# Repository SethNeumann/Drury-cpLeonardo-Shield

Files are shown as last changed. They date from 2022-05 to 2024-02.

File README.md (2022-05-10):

# REPO NAME: Drury-cpLeonardo-Shield

## License: Creative Commons Attribution-NonCommercial-ShareAlike

The original cpNode used a Leonardo-based protoyping board called a BB-Leo.  Chuck Catania like Leonardo because the
2nd serial port made for easier serial debugging as the cpNode needed D0/D1 (TX/RX) to implement the CMRINet.  In 2021
Modern Device discontinued the BB-Leo, so we moved the basic cpNode to the ProMini resulting in the cpNode-PM, we also made 
an adapter board with a Pro-Mini that fit into a standard cpNode, called a BB-ProMini.

Dennis Drury like the Leonardo and wanted to keep the code compatible, so he designed this shield form factor board that 
plugs onto a standard (Uno form factor) Leonardo.  It supports the I2C chain so you can use standard IOXs (or any other
shield you like if you want to write customer code).  

This is a great complement to cpNode, cpNode-PM, Andrew Deak's MegaNode and of course the classic JLC SMINI and SUSIC.

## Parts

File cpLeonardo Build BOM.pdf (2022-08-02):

Qty | Value | Device | Package | Parts | Description
| 1 0.1uF | CAPPTH2 | C-PTH-0.100 | C1
| 4 0.01uF | CAPPTH2 | C-PTH-0.100 | C2, C3, C4, C5
| 3 0.100 | CONNECTOR-M06SIP_LOCK | 1X06-SIP_LOCK | CON4, CON6, CON7 | Arduino Header 6 Standard 6-pin 0.1 header"
| 1 1N4148 | DIODE1N4148 | DIODE-1N4148 | D1 | Diode
| 1 0.100 | M02POLAR_LOCK | MOLEX-1X4_LOCK | GND, LEDCOM | Header 2
| 1 0.100 | PINHD-1X4/90 | 1X04/90 | I2CHDR | right angle I2C headers
| 4 0.100 | M081X08 | 1X08 | IO1, IO2, IO3, IO5 | machine pin header for resistors
2 0.100 | CONNECTOR-M08LOCK_LONGPADS | 1X08_LOCK_LONGPADS J1, J2 | input/output screw terminals
1 | CONN_08SILK_FEMALE_PTH | 1X08 | CON5 | Multi connection point.
| 1 12k | RPTH04 | AXIAL-0.4-RES | R1 | Resistor (Auto RTS - see schemativ)
| 1 470 | RPTH04 | AXIAL-0.4-RES | R2 | Resistor
| 0 0.156 | CONNECTOR-CMRINET.156 | KK-156-5 | RS485-1, RS485-2 | CMRINet Top 3.5mm Screw Terminal 5 pos
| 2 3.5mm | CONNECTOR-CMRINET3.5MM | CMRINET-3.5MM | RS485-3, RS485-4 | CMRINet Top 3.5mm Screw Terminal 5 pos
| 1 G | LEDLED3MM | LED3MM | TX
1 MAX3465CPD MAX3465CPD | DIL14 | U1 | +5V, Fail-Safe, 40Mbps, Profibus RS-485/RS-422 Transceivers
| 1 NE555P | NE555P | DIL-08 | U2 | General purpose bipolar Timer
| 1 8 pin | socket | DIL8
| 1 14 pin | socket | DIL14
| 1 cpLeonardo | board | Uno Shield

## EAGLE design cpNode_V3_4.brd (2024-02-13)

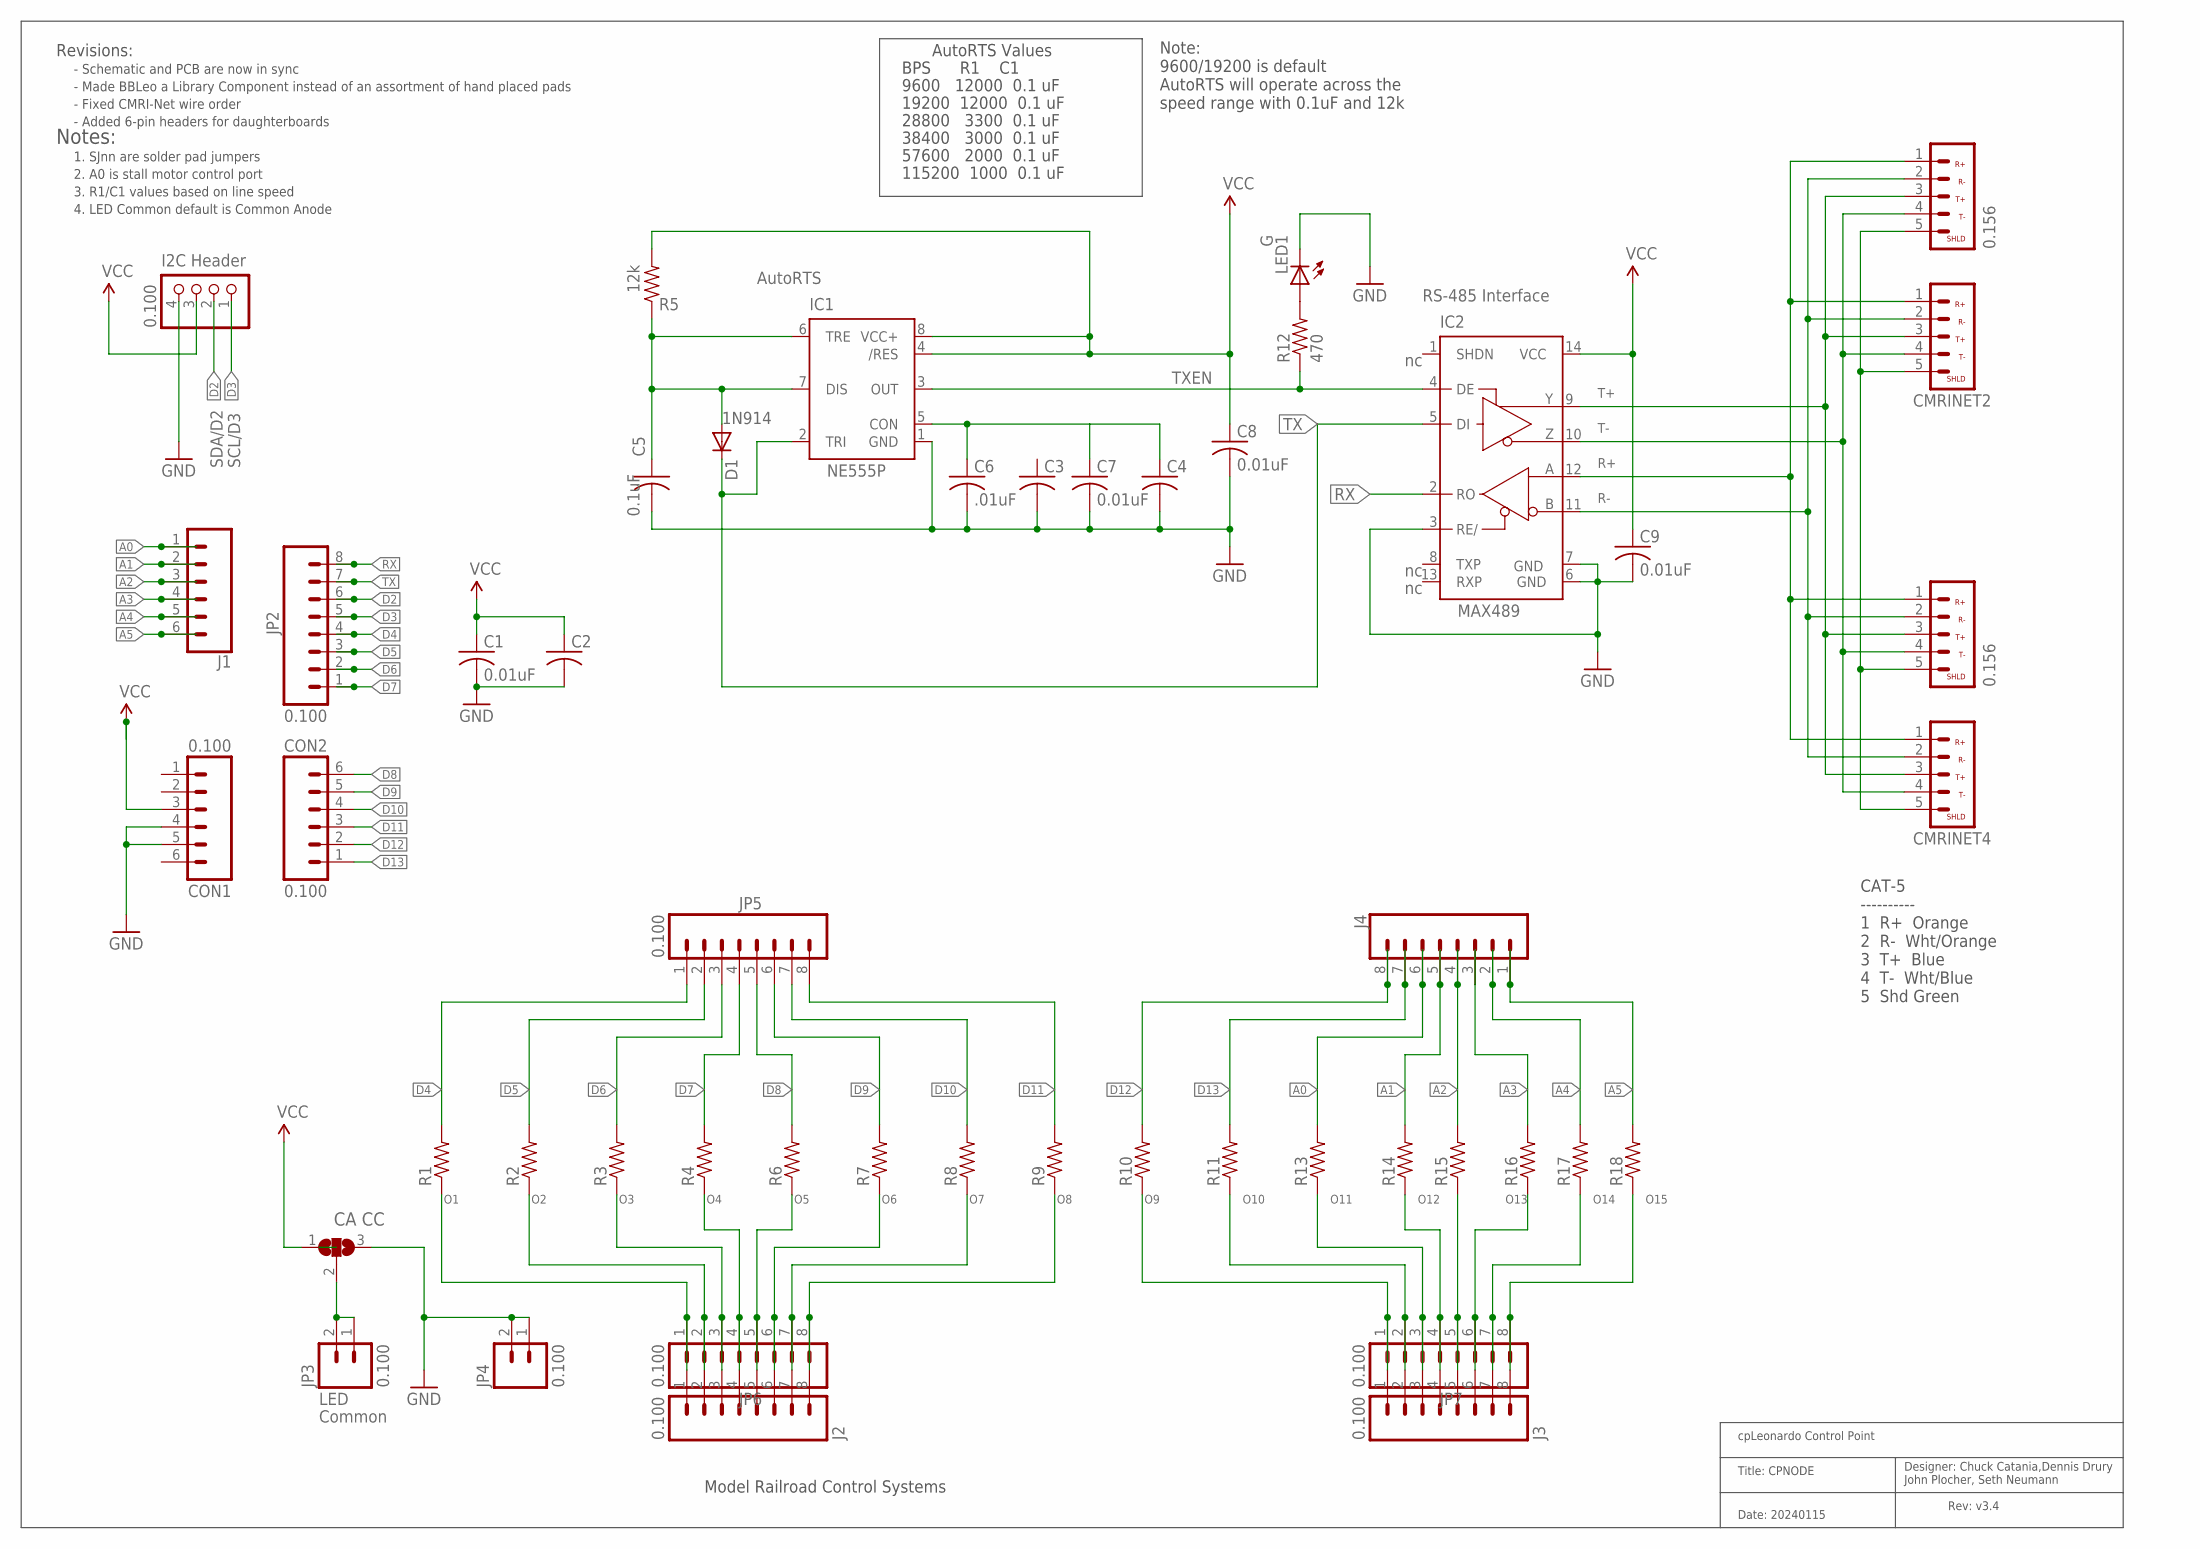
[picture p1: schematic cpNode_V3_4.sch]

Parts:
C1, C7, C8, C9: 0.01uF; C-PTH-0.100
C2, C3, C4: CAPPTH1; C050-024X044
C5: 0.1uF; C-PTH-0.100
C6: .01uF; C050-024X044
CMRINET1, CMRINET3: 0.156; KK-156-5
CMRINET2, CMRINET4: 3.5mm; CMRINET-3.5MM
CON1, CON2: 0.100; 1X06-SIP_LOCK
D1: 1N4148; DIODE-1N4148
IC1: NE555P; DIL-08
IC2: MAX3465CPD; DIL14
J1: CONN_06SILK_FEMALE_PTH; 1X06
J2, J3: 0.100; 1X08_LOCK_LONGPADS
J4: CONN_08"; 1X08
JP1: 0.100; 1X04/90
JP2, JP5, JP6, JP7: 0.100; 1X08
JP3, JP4: 0.100; MOLEX-1X2_LOCK
LED1: G; LED3MM
P1: CA CC; 3P-SMD-2X4.8
R1, R2, R3, R4, R6, R7, R8, R9, R10, R11, R13, R14, R15, R16, R17, R18: RPTH-R0; CUT-R
R5: 12k; AXIAL-0.4-RES
R12: 470; AXIAL-0.4-RES

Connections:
A0: J1.1, J4.6, R13.P1 (2)
A1: J1.2, J4.5, R14.P1 (2)
A2: J1.3, J4.4, R15.P1 (2)
A3: J1.4, J4.3, R16.P1 (2)
A4: J1.5, J4.2, R17.P1 (2)
A5: J1.6, J4.1, R18.P1 (2)
D2: JP1.2, JP2.6
D3: JP1.1, JP2.5
D4: JP2.4, JP5.1, R1.P1 (2)
D5: JP2.3, JP5.2, R2.P1 (2)
D6: JP2.2, JP5.3, R3.P1 (2)
D7: JP2.1, JP5.4, R4.P1 (2)
D8: CON2.6, JP5.5, R6.P1 (2)
D9: CON2.5, JP5.6, R7.P1 (2)
D10: CON2.4, JP5.7, R8.P1 (2)
D11: CON2.3, JP5.8, R9.P1 (2)
D12: CON2.2, J4.8, R10.P1 (2)
D13: CON2.1, J4.7, R11.P1 (2)
GND: C1.2, C2.2, C3.2, C4.2, C5.2, C6.2, C7.2, C8.2, C9.2, CON1.4, CON1.5, IC1.1 (GND), IC2.3 (RE/), IC2.6 (GND), IC2.7 (GND), JP1.4, JP4.1, JP4.2, LED1.K (C), P1.3
unnamed: LED1.A, R12.P$2 (2)
unnamed: C4.1, C6.1, C7.1, IC1.5 (CON)
unnamed: JP3.1, JP3.2, P1.2
unnamed: C5.1, D1.A, IC1.6 (TRE), IC1.7 (DIS), R5.P$1 (1)
unnamed: IC1.3 (OUT), IC2.4 (DE), R12.P$1 (1)
O1: J2.1, JP6.1, R1.P2 (1)
O2: J2.2, JP6.2, R2.P2 (1)
O3: J2.3, JP6.3, R3.P2 (1)
O4: J2.4, JP6.4, R4.P2 (1)
O5: J2.5, JP6.5, R6.P2 (1)
O6: J2.6, JP6.6, R7.P2 (1)
O7: J2.7, JP6.7, R8.P2 (1)
O8: J2.8, JP6.8, R9.P2 (1)
O9: J3.1, JP7.1, R10.P2 (1)
O10: J3.2, JP7.2, R11.P2 (1)
O11: J3.3, JP7.3, R13.P2 (1)
O12: J3.4, JP7.4, R14.P2 (1)
O13: J3.5, JP7.5, R15.P2 (1)
O14: J3.6, JP7.6, R16.P2 (1)
O15: J3.7, JP7.7, R17.P2 (1)
O16: J3.8, JP7.8, R18.P2 (1)
R+: CMRINET1.1, CMRINET2.1, CMRINET3.1, CMRINET4.1, IC2.12 (A)
R-: CMRINET1.2, CMRINET2.2, CMRINET3.2, CMRINET4.2, IC2.11 (B)
RX: IC2.2 (RO), JP2.8
SHIELD: CMRINET1.5, CMRINET2.5, CMRINET3.5, CMRINET4.5
T+: CMRINET1.3, CMRINET2.3, CMRINET3.3, CMRINET4.3, IC2.9 (Y)
T-: CMRINET1.4, CMRINET2.4, CMRINET3.4, CMRINET4.4, IC2.10 (Z)
TX: D1.C, IC1.2 (TRI), IC2.5 (DI), JP2.7
VCC: C1.1, C2.1, C8.1, C9.1, CON1.3, IC1.4 (/RES), IC1.8 (VCC+), IC2.14 (VCC), JP1.3, P1.1, R5.P$2 (2)

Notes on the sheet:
Rev: v3.4
Date: 20240115
Title: CPNODE
cpLeonardo Control Point
Designer: Chuck Catania,Dennis Drury John Plocher, Seth Neumann
SDA/D2
SCL/D3
TXEN
LED
1N914
MAX489
RS-485 Interface
Notes:
1. SJnn are solder pad jumpers
2. A0 is stall motor control port
I2C Header
3. R1/C1 values based on line speed
AutoRTS
AutoRTS Values
9600 12000 0.1 uF
19200 12000 0.1 uF
38400 3000 0.1 uF
57600 2000 0.1 uF
115200 1000 0.1 uF
BPS R1 C1
Common
4. LED Common default is Common Anode
Model Railroad Control Systems
Revisions:
CAT-5 ---------- 1 R+ Orange 2 R- Wht/Orange 3 T+ Blue 4 T- Wht/Blue 5 Shd Green
28800 3300 0.1 uF
Note: 9600/19200 is default AutoRTS will operate across the speed range with 0.1uF and 12k
- Fixed CMRI-Net wire order
- Schematic and PCB are now in sync
- Made BBLeo a Library Component instead of an assortment of hand placed pads
- Added 6-pin headers for daughterboards

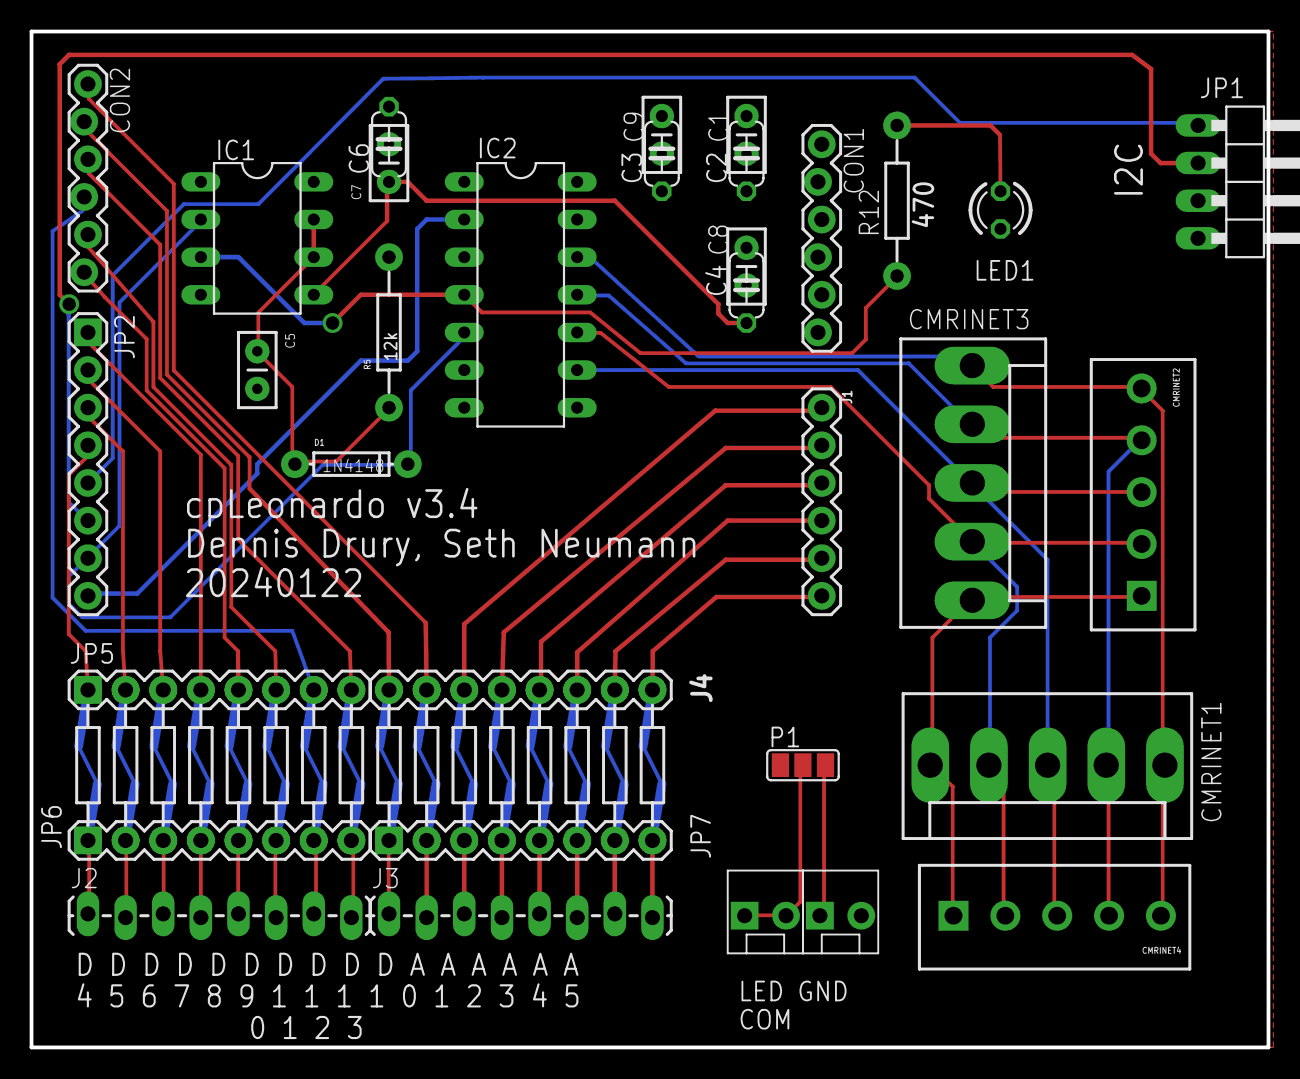
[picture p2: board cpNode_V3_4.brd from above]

Board: 2 copper layers, 83.5 x 68.6 mm, 52 parts (1 on the bottom side), 48 nets.

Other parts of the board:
U$1: CA-PROP65WARNING
U$2: MRCSLOGOBTM
U$3: MRCSLOGOTOP

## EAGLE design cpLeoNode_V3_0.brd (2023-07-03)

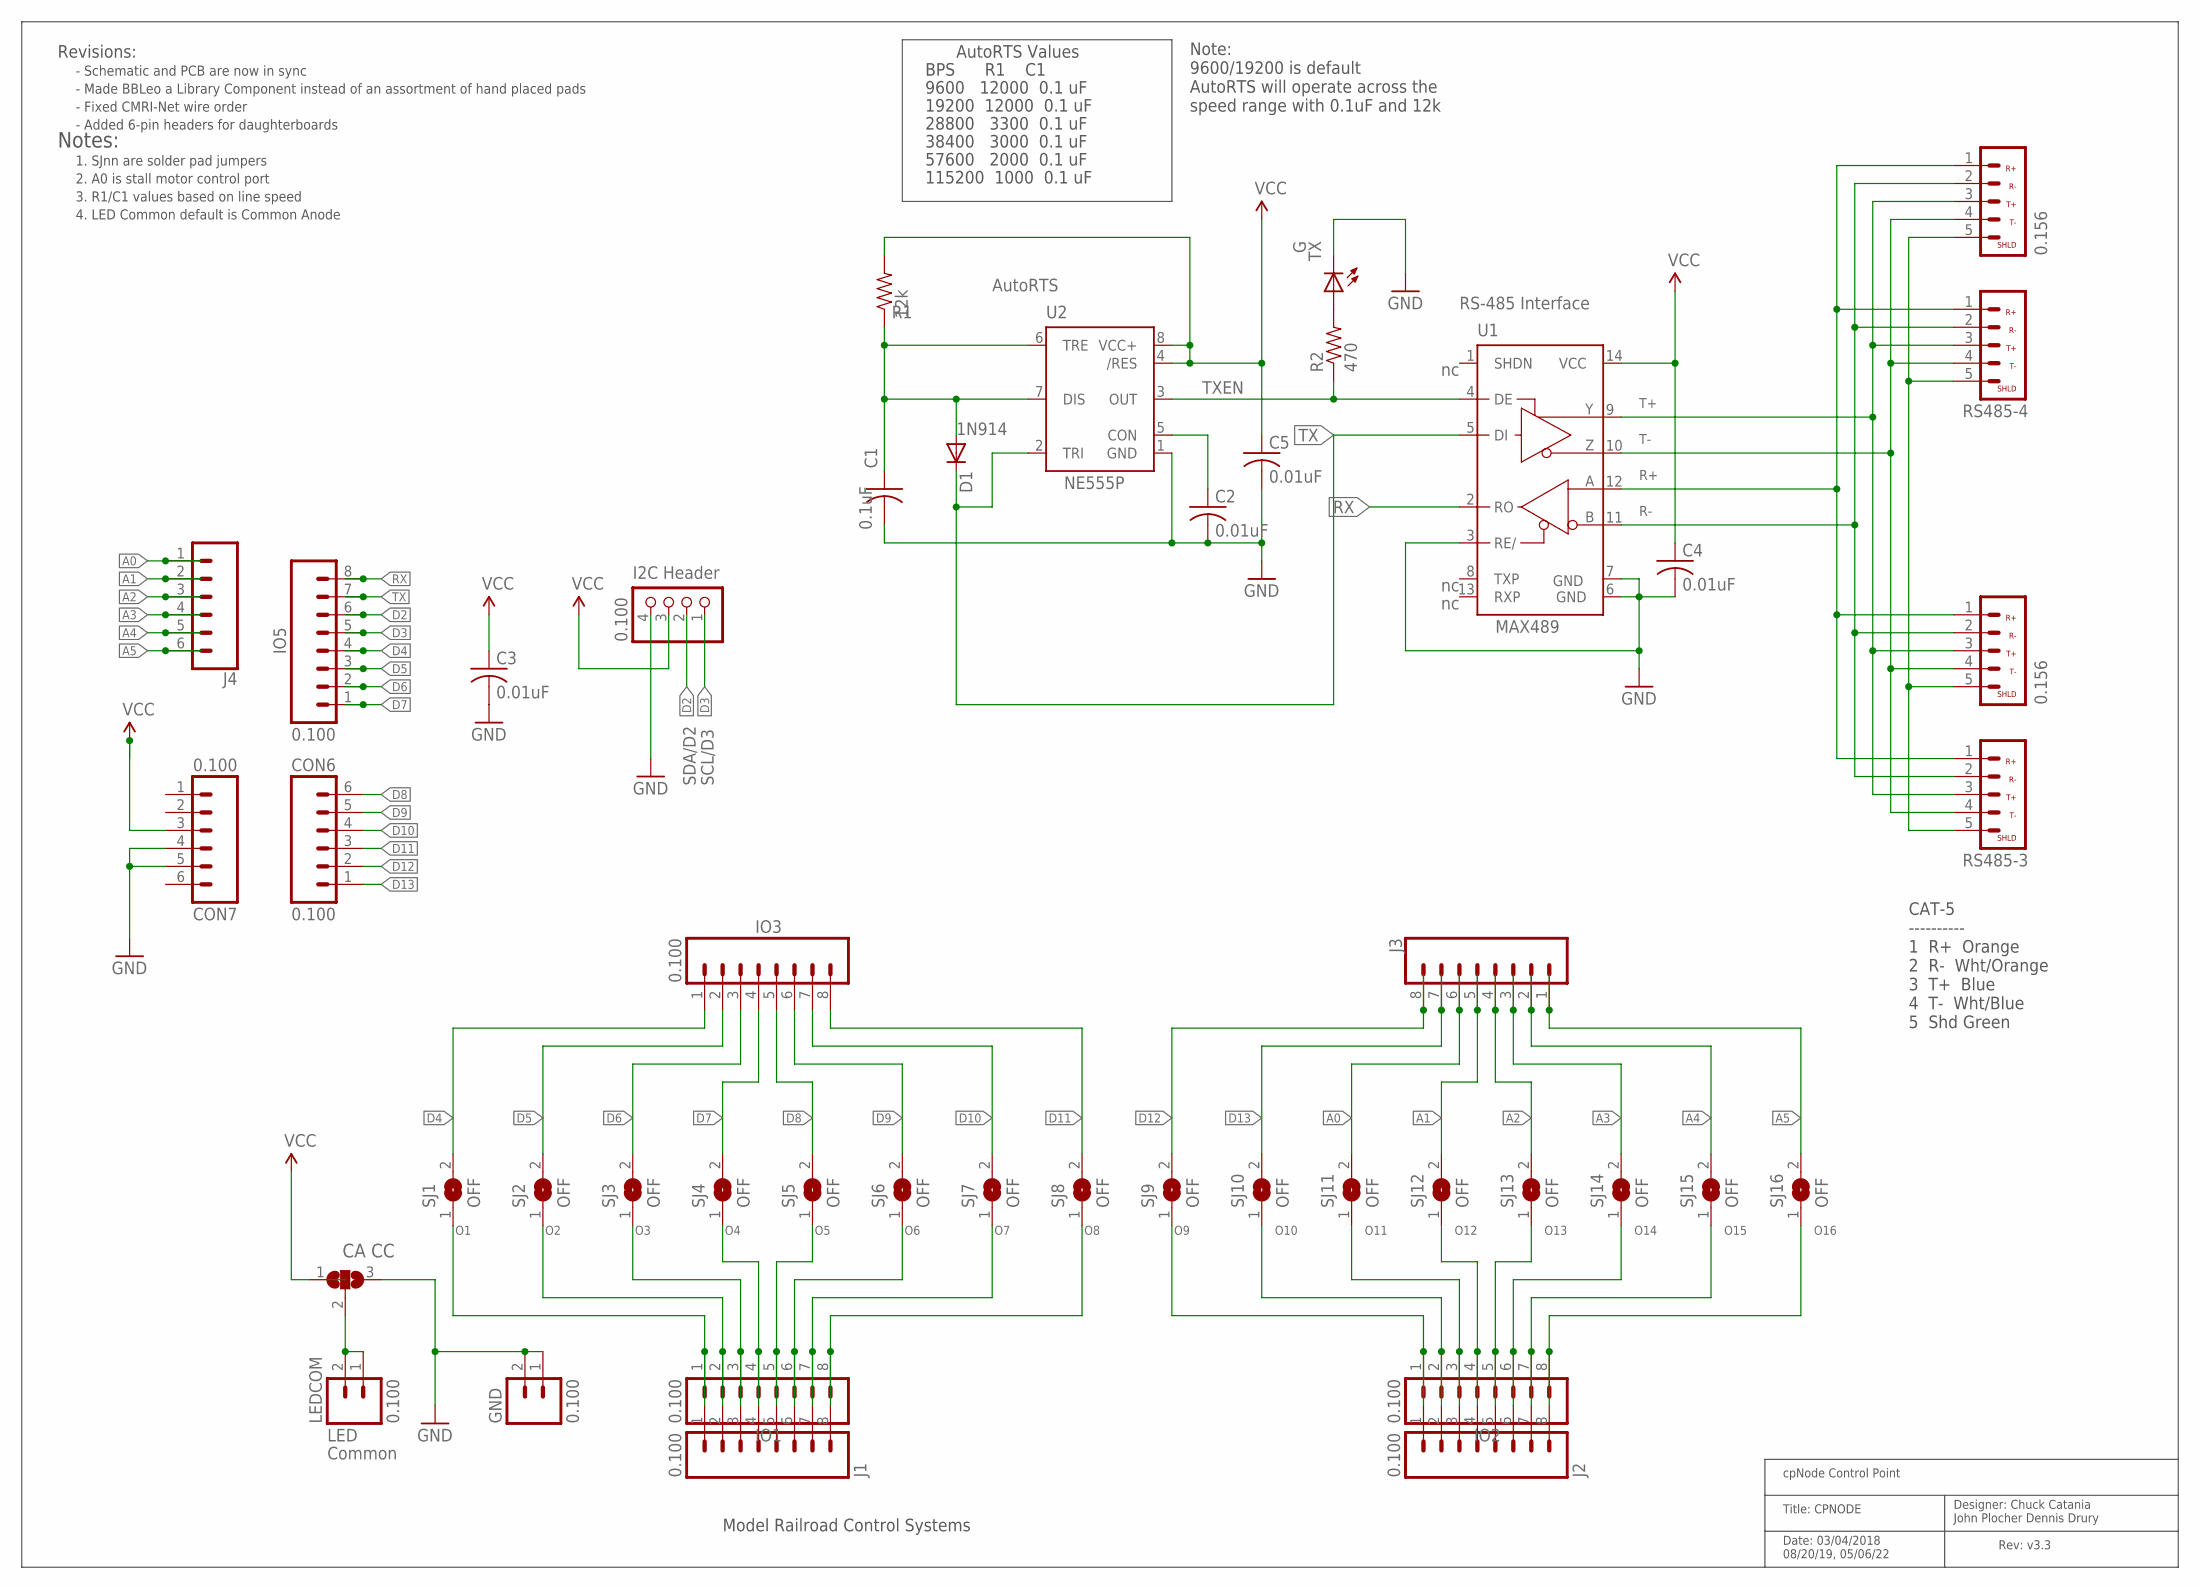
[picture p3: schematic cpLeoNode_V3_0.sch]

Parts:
C1: 0.1uF; C-PTH-0.100
C2, C3, C4, C5: 0.01uF; C-PTH-0.100
CON6, CON7: 0.100; 1X06-SIP_LOCK
D1: 1N4148; DIODE-1N4148
GND: 0.100; MOLEX-1X2_LOCK
I2CHDR: 0.100; 1X04/90
IO1, IO2, IO3, IO5: 0.100; 1X08
J1, J2: 0.100; 1X08_LOCK_LONGPADS
J3: CONN_08"; 1X08
J4: CONN_06SILK_FEMALE_PTH; 1X06
LEDCOM: 0.100; MOLEX-1X2_LOCK
P1: CA CC; 3P-SMD-2X4.8
R1: 12k; AXIAL-0.4-RES
R2: 470; AXIAL-0.4-RES
RS485-1, RS485-2: 0.156; KK-156-5
RS485-3, RS485-4: 3.5mm; CMRINET-3.5MM
SJ1, SJ2, SJ3, SJ4, SJ5, SJ6, SJ7, SJ8, SJ9, SJ10, SJ11, SJ12, SJ13, SJ14, SJ15, SJ16: OFF; SJ
TX: G; LED3MM
U1: MAX3465CPD; DIL14
U2: NE555P; DIL-08

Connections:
A0: J3.6, J4.1, SJ11.2
A1: J3.5, J4.2, SJ12.2
A2: J3.4, J4.3, SJ13.2
A3: J3.3, J4.4, SJ14.2
A4: J3.2, J4.5, SJ15.2
A5: J3.1, J4.6, SJ16.2
D2: I2CHDR.2, IO5.6
D3: I2CHDR.1, IO5.5
D4: IO3.1, IO5.4, SJ1.2
D5: IO3.2, IO5.3, SJ2.2
D6: IO3.3, IO5.2, SJ3.2
D7: IO3.4, IO5.1, SJ4.2
D8: CON6.6, IO3.5, SJ5.2
D9: CON6.5, IO3.6, SJ6.2
D10: CON6.4, IO3.7, SJ7.2
D11: CON6.3, IO3.8, SJ8.2
D12: CON6.2, J3.8, SJ9.2
D13: CON6.1, J3.7, SJ10.2
GND: C1.2, C2.2, C3.2, C4.2, C5.2, CON7.4, CON7.5, GND.1, GND.2, I2CHDR.4, P1.3, TX.K (C), U1.3 (RE/), U1.6 (GND), U1.7 (GND), U2.1 (GND)
unnamed: R2.P$2 (2), TX.A
unnamed: C2.1, U2.5 (CON)
unnamed: LEDCOM.1, LEDCOM.2, P1.2
unnamed: C1.1, D1.A, R1.P$1 (1), U2.6 (TRE), U2.7 (DIS)
unnamed: R2.P$1 (1), U1.4 (DE), U2.3 (OUT)
O1: IO1.1, J1.1, SJ1.1
O2: IO1.2, J1.2, SJ2.1
O3: IO1.3, J1.3, SJ3.1
O4: IO1.4, J1.4, SJ4.1
O5: IO1.5, J1.5, SJ5.1
O6: IO1.6, J1.6, SJ6.1
O7: IO1.7, J1.7, SJ7.1
O8: IO1.8, J1.8, SJ8.1
O9: IO2.1, J2.1, SJ9.1
O10: IO2.2, J2.2, SJ10.1
O11: IO2.3, J2.3, SJ11.1
O12: IO2.4, J2.4, SJ12.1
O13: IO2.5, J2.5, SJ13.1
O14: IO2.6, J2.6, SJ14.1
O15: IO2.7, J2.7, SJ15.1
O16: IO2.8, J2.8, SJ16.1
R+: RS485-1.1, RS485-2.1, RS485-3.1, RS485-4.1, U1.12 (A)
R-: RS485-1.2, RS485-2.2, RS485-3.2, RS485-4.2, U1.11 (B)
RX: IO5.8, U1.2 (RO)
SHIELD: RS485-1.5, RS485-2.5, RS485-3.5, RS485-4.5
T+: RS485-1.3, RS485-2.3, RS485-3.3, RS485-4.3, U1.9 (Y)
T-: RS485-1.4, RS485-2.4, RS485-3.4, RS485-4.4, U1.10 (Z)
TX: D1.C, IO5.7, U1.5 (DI), U2.2 (TRI)
VCC: C3.1, C4.1, C5.1, CON7.3, I2CHDR.3, P1.1, R1.P$2 (2), U1.14 (VCC), U2.4 (/RES), U2.8 (VCC+)

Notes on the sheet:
Rev: v3.3
Date: 03/04/2018 08/20/19, 05/06/22
Title: CPNODE
cpNode Control Point
Designer: Chuck Catania John Plocher Dennis Drury
SDA/D2
SCL/D3
TXEN
LED
1N914
MAX489
RS-485 Interface
Notes:
1. SJnn are solder pad jumpers
2. A0 is stall motor control port
I2C Header
3. R1/C1 values based on line speed
AutoRTS
AutoRTS Values
9600 12000 0.1 uF
19200 12000 0.1 uF
38400 3000 0.1 uF
57600 2000 0.1 uF
115200 1000 0.1 uF
BPS R1 C1
Common
4. LED Common default is Common Anode
Model Railroad Control Systems
Revisions:
CAT-5 ---------- 1 R+ Orange 2 R- Wht/Orange 3 T+ Blue 4 T- Wht/Blue 5 Shd Green
28800 3300 0.1 uF
Note: 9600/19200 is default AutoRTS will operate across the speed range with 0.1uF and 12k
- Fixed CMRI-Net wire order
- Schematic and PCB are now in sync
- Made BBLeo a Library Component instead of an assortment of hand placed pads
- Added 6-pin headers for daughterboards

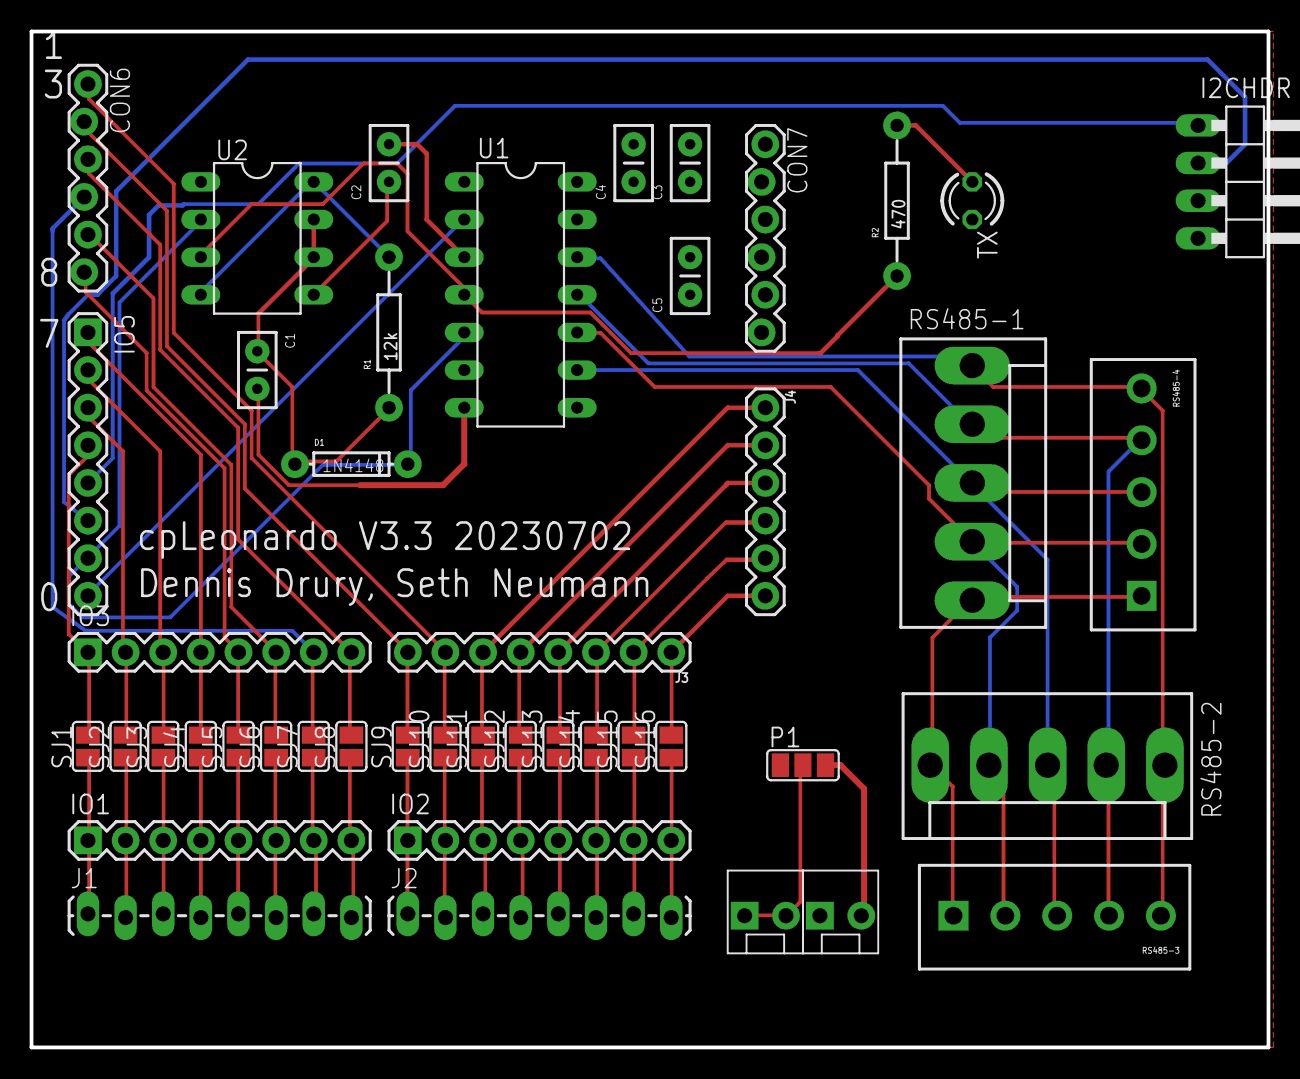
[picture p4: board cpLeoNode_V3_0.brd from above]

Board: 2 copper layers, 83.5 x 68.6 mm, 47 parts (0 on the bottom side), 48 nets.

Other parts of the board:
U$1: CA-PROP65WARNING
U$2: MRCSLOGOBTM

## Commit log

2022-05-10 integrating files from Dennis
    This Dennis' original file with a ground plane added
    [EagleTemplate-new.brd, EagleTemplate-new.sch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]
2022-07-05 adjustments of Leonardo header to fit better
    [cpLeoNode_V3_0.brd, cpLeoNode_V3_0.sch]
2022-08-02 Create cpLeonardo Build BOM.pdf
2023-07-03 A bunch of cleanup after moving things around
    1 - move Arduino connectors closer together for better fit with the Leonardo
    2 - added VCC plane and removed a lot of old VCC and GND traces
    3- added labels on top to help orient Leonardo
    4 - mirrored bottom labels and moved to bplace for readability
    [cpLeoNode_V3_0.brd, cpLeoNode_V3_0.sch]
2024-02-13 version 3.4
    moved to cuttable resistors
    [cpNode_V3_4.brd, cpNode_V3_4.sch]

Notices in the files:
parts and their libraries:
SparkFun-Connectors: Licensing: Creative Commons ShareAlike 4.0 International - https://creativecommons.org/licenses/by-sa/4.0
